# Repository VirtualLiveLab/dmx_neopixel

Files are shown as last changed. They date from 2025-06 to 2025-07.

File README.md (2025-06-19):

# dmx neopixel
DMX信号をNeoPixelの信号に変換する基板

## 基板設計
- KiCad 9.0で作成
- [JLCPCB](https://jlcpcb.com)に発注
- 部品はほぼ全て秋月電子通商にて購入可能(XLRのレセプタクルのみサウンドハウスで購入)

## ファームウェア書き込み
- [PlatformIO Core](https://docs.platformio.org/en/latest/core/index.html)をインストール
  - [get-platformio.py](https://raw.githubusercontent.com/platformio/platformio-core-installer/master/get-platformio.py)をダウンロードしてPython3で実行
- USBで基板をPCに接続
- 書き込みコマンド実行

```bash
cd ./platformio/
pio run
```

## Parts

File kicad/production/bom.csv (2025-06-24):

Designator | Footprint | Quantity | Value | LCSC Part #
C1, C2, C5, C8 | 0603 | 4 | 0.1u
C3, C6, C7 | 0603 | 3 | 1u
C4 | 0603 | 1 | 10u
D1, D2 | D_SOD-123F | 2 | SS2040FL
D3 | LED_WS2812B-2020_PLCC4_2.0x2.0mm | 1 | WS2812C-2020
F1 | Fuse_Bourns_MF-RHT050 | 1 | MF-R050
J1 | BarrelJack_Horizontal | 1 | Jack-DC
J2 | USB_C_Receptacle_GCT_USB4105-xx-A_16P_TopMnt_Horizontal | 1 | USB_C_Receptacle_USB2.0_16P
J3 | JST_XH_S2B-XH-A_1x02_P2.50mm_Horizontal | 1 | Conn_01x02_Pin
J4 | Jack_XLR_Neutrik_NC3MAH_Horizontal | 1 | NC3MAH
J5 | Jack_XLR_Neutrik_NC3FAH2_Horizontal | 1 | NC3FAH2
Q1 | SOT-23 | 1 | BSS138
R1, R2 | 0603 | 2 | 5.1k
R3, R4, R5 | 0603 | 3 | 10k
SW1 | SW_SPST_PTS810 | 1 | SW_Push
SW2 | SW_DIP_SPSTx10_Slide_6.7x26.96mm_W7.62mm_P2.54mm_LowProfile | 1 | SW_DIP_x10
U1 | SIP3_11.6x8.5mm | 1 | BP5293-50
U2 | SOT-23 | 1 | AP7333-33SA
U3 | ESP32-C3-WROOM-02 | 1 | ESP32-C3-WROOM-02
U4 | SOIC-8_3.9x4.9mm_P1.27mm | 1 | MAX3485

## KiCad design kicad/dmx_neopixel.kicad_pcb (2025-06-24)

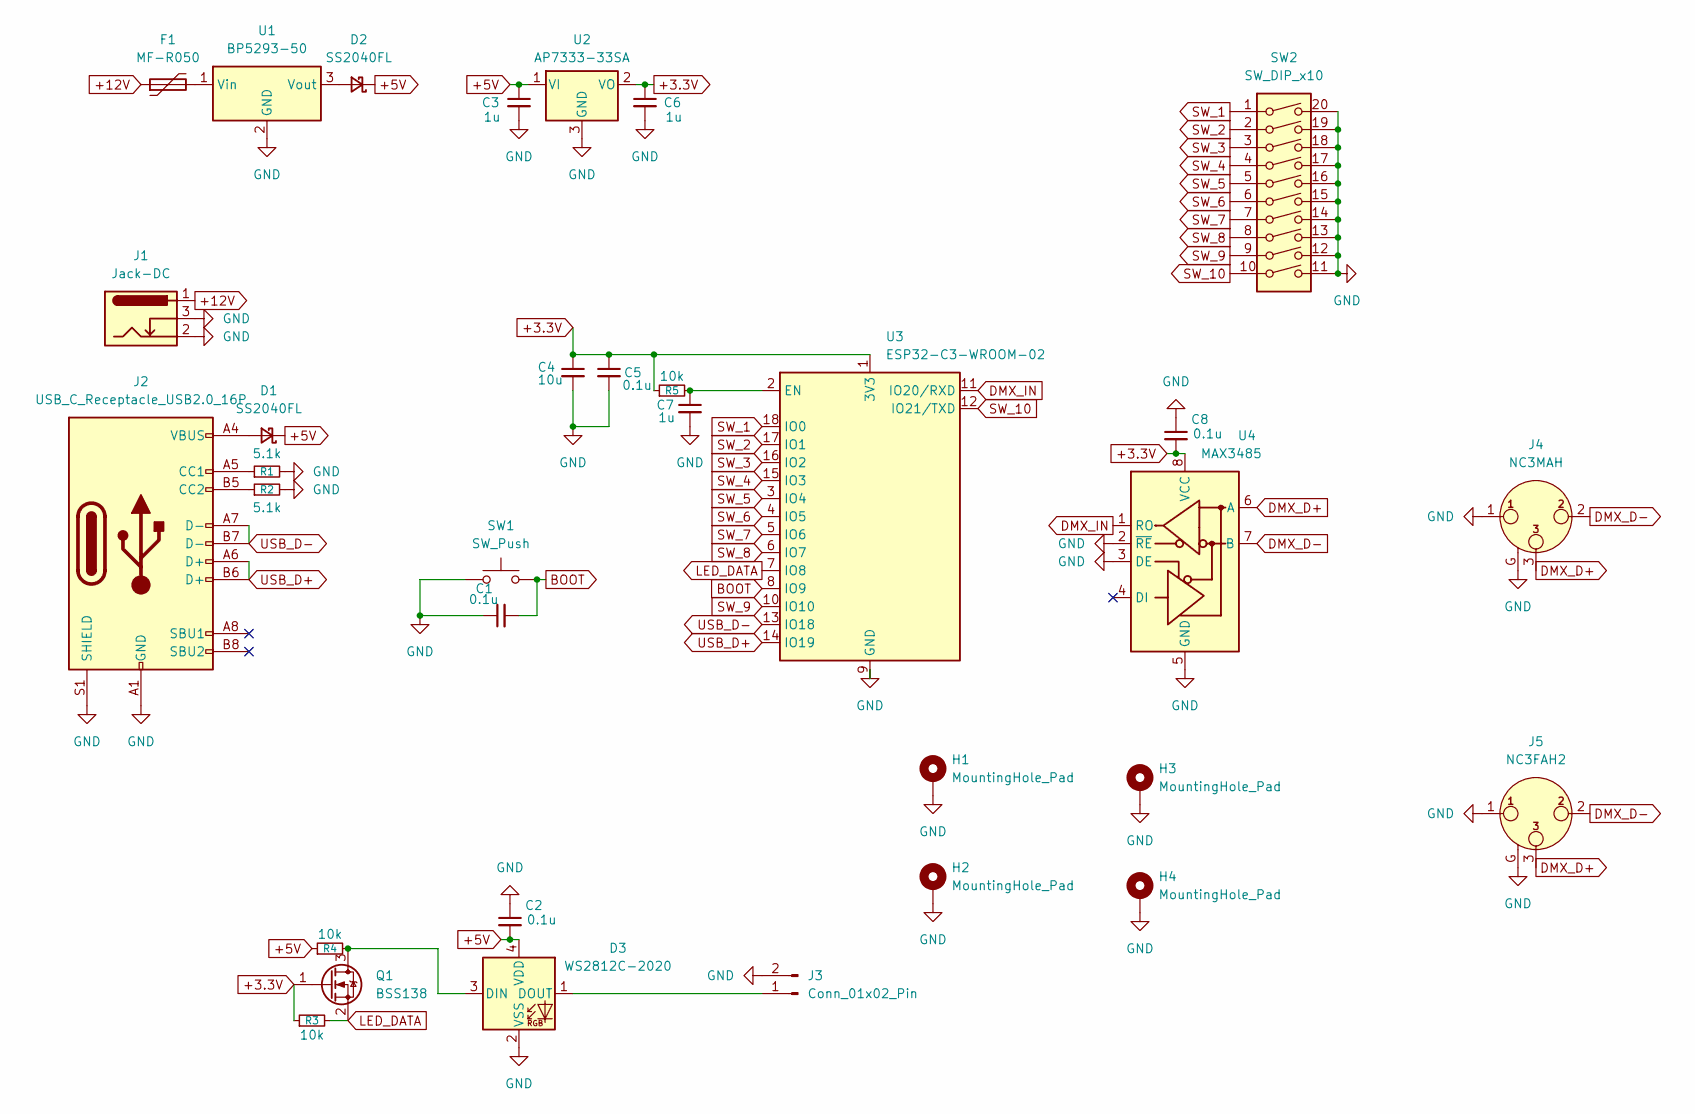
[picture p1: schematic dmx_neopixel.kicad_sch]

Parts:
C1, C2, C5, C8: 0.1u; C_0603_1608Metric_Pad1.08x0.95mm_HandSolder
C3, C6, C7: 1u; C_0603_1608Metric_Pad1.08x0.95mm_HandSolder
C4: 10u; C_0603_1608Metric_Pad1.08x0.95mm_HandSolder
D1, D2: SS2040FL; D_SOD-123F
D3: WS2812C-2020; LED_WS2812B-2020_PLCC4_2.0x2.0mm
F1: MF-R050; Fuse_Bourns_MF-RHT050
H1, H2, H3, H4: MountingHole_Pad; MountingHole_3.2mm_M3_Pad_TopBottom
J1: Jack-DC; BarrelJack_Horizontal
J2: USB_C_Receptacle_USB2.0_16P; USB_C_Receptacle_GCT_USB4105-xx-A_16P_TopMnt_Horizontal
J3: Conn_01x02_Pin; JST_XH_S2B-XH-A_1x02_P2.50mm_Horizontal
J4: NC3MAH; Jack_XLR_Neutrik_NC3MAH_Horizontal
J5: NC3FAH2; Jack_XLR_Neutrik_NC3FAH2_Horizontal
Q1: BSS138; SOT-23
R1, R2: 5.1k; R_0603_1608Metric_Pad0.98x0.95mm_HandSolder
R3, R4, R5: 10k; R_0603_1608Metric_Pad0.98x0.95mm_HandSolder
SW1: SW_Push; SW_SPST_PTS810
SW2: SW_DIP_x10; SW_DIP_SPSTx10_Slide_6.7x26.96mm_W7.62mm_P2.54mm_LowProfile
U1: BP5293-50; SIP3_11.6x8.5mm
U2: AP7333-33SA; SOT-23
U3: ESP32-C3-WROOM-02
U4: MAX3485; SOIC-8_3.9x4.9mm_P1.27mm

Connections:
+3.3V: C4.1, C5.1, C6.1, C8.2, Q1.1 (G), R3.1, R5.1, U2.2 (VO), U3.1 (3V3), U4.8 (VCC)
+5V: C2.2, C3.1, D1.1 (K), D2.1 (K), D3.4 (VDD), R4.1, U2.1 (VI)
+12V: F1.1, J1.1
BOOT: C1.2, SW1.2, U3.8 (IO9)
DMX_D+: J4.3, J5.3, U4.6 (A)
DMX_D-: J4.2, J5.2, U4.7 (B)
DMX_IN: U3.11 (IO20/RXD), U4.1 (RO)
GND: C1.1, C2.1, C3.2, C4.2, C5.2, C6.2, C7.2, C8.1, D3.2 (VSS), H1.1, H2.1, H3.1, H4.1, J1.2, J1.3, J2.A1 (GND), J2.A12 (GND), J2.B1 (GND), J2.B12 (GND), J2.S1 (SHIELD), J3.2, J4.1, J4.G, J5.1, J5.G, R1.2, R2.2, SW1.1, SW2.11, SW2.12, SW2.13, SW2.14, SW2.15, SW2.16, SW2.17, SW2.18, SW2.19, SW2.20, U1.2 (GND), U2.3 (GND), U3.9 (GND), U3.19 (GND), U4.2 (~RE), U4.3 (DE), U4.5 (GND)
LED_DATA: Q1.2 (S), R3.2, U3.7 (IO8)
unnamed: D1.2 (A), J2.A4 (VBUS), J2.A9 (VBUS), J2.B4 (VBUS), J2.B9 (VBUS)
unnamed: D2.2 (A), U1.3 (Vout)
unnamed: D3.3 (DIN), Q1.3 (D), R4.2
unnamed: D3.1 (DOUT), J3.1
unnamed: J2.A5 (CC1), R1.1
unnamed: J2.B5 (CC2), R2.1
unnamed: F1.2, U1.1 (Vin)
unnamed: C7.1, R5.2, U3.2 (EN)
SW_1: SW2.1, U3.18 (IO0)
SW_2: SW2.2, U3.17 (IO1)
SW_3: SW2.3, U3.16 (IO2)
SW_4: SW2.4, U3.15 (IO3)
SW_5: SW2.5, U3.3 (IO4)
SW_6: SW2.6, U3.4 (IO5)
SW_7: SW2.7, U3.5 (IO6)
SW_8: SW2.8, U3.6 (IO7)
SW_9: SW2.9, U3.10 (IO10)
SW_10: SW2.10, U3.12 (IO21/TXD)
USB_D+: J2.A6 (D+), J2.B6 (D+), U3.14 (IO19)
USB_D-: J2.A7 (D-), J2.B7 (D-), U3.13 (IO18)

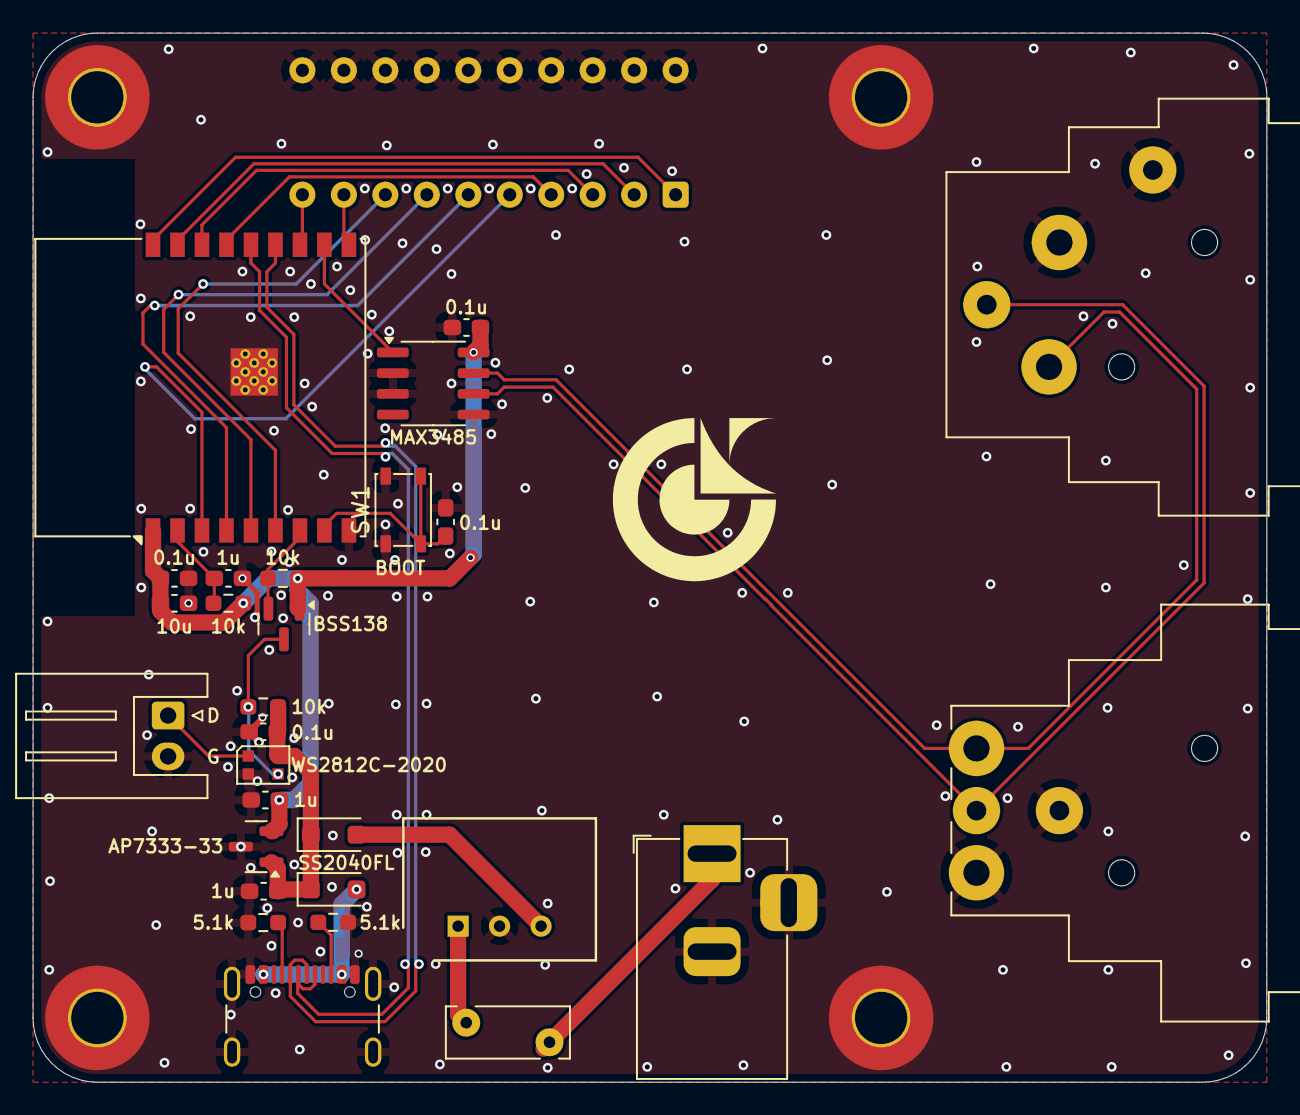
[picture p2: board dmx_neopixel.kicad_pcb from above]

Board: 2 copper layers, 75.6 x 64.3 mm, 33 parts (1 on the bottom side), 29 nets.

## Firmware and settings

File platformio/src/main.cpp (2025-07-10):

#include <Arduino.h>
#include <esp_dmx.h>
#include <NeoPixelBus.h>
#include <Preferences.h>
#include <CRC32.h>
#include <PacketSerial.h>

#define VERSION 0x20  // v2.0
#define DATASIZE 2041
#define BUFFSIZE 4096
#define LEDNUM 961
#define LEDPIN 8
#define DMXPIN 20
#define INDICATOR_BRIGHTNESS 10

NeoPixelBus<NeoGrbFeature, NeoEsp32Rmt0Ws2812xMethod> leds(LEDNUM, LEDPIN);
PacketSerial_<COBS, 0, BUFFSIZE> packetSerial;
Preferences preferences;
uint8_t cache[DATASIZE];
byte dmxData[DMX_PACKET_SIZE];
SemaphoreHandle_t showSemaphore;

volatile unsigned long retry = 0;

uint8_t validateCRC(const uint8_t* buffer, size_t size) {
  uint32_t crcInBuff = ((uint32_t)buffer[size - 4] << 24) |
    ((uint32_t)buffer[size - 3] << 16) |
    ((uint32_t)buffer[size - 2] << 8)  |
    ((uint32_t)buffer[size - 1]);
  uint32_t crc = CRC32::calculate(buffer, size - 4);
  if (crcInBuff != crc) return 1;
  return 0;
}

void onPacketReceived(const uint8_t* buffer, size_t size) {
  uint8_t resBuff[DATASIZE + 6];
  resBuff[0] = VERSION;
  if (validateCRC(buffer, size) == 0) {
    if (buffer[1] == 0x00) {
      resBuff[1] = 0x00;
      memcpy(resBuff + 2, cache, DATASIZE);
      uint32_t crc = CRC32::calculate(resBuff, DATASIZE + 2);
      resBuff[DATASIZE + 2] = (crc >> 24);
      resBuff[DATASIZE + 3] = (crc >> 16);
      resBuff[DATASIZE + 4] = (crc >> 8);
      resBuff[DATASIZE + 5] = crc;
      packetSerial.send(resBuff, DATASIZE + 6);
      return;
    } else if (buffer[0] == VERSION && buffer[1] == 0x01) {
      memcpy(cache, buffer + 2, DATASIZE);
      if (preferences.putBytes("data", cache, DATASIZE) > 0) {
        resBuff[1] = 0x00;
        uint32_t crc = CRC32::calculate(resBuff, 2);
        resBuff[2] = (crc >> 24);
        resBuff[3] = (crc >> 16);
        resBuff[4] = (crc >> 8);
        resBuff[5] = crc;
        packetSerial.send(resBuff, 6);
        return;
      }
    }
  }
  resBuff[1] = 0x01;
  uint32_t crc = CRC32::calculate(resBuff, 2);
  resBuff[2] = (crc >> 24);
  resBuff[3] = (crc >> 16);
  resBuff[4] = (crc >> 8);
  resBuff[5] = crc;
  packetSerial.send(resBuff, 6);
}

void showTask(void* pvParameters) {
  TickType_t lastWake = xTaskGetTickCount();
  for (;;) {
    if (xSemaphoreTake(showSemaphore, portMAX_DELAY) == pdTRUE) {
      if (leds.CanShow()) {
        leds.Show();
      }
    }
    vTaskDelayUntil(&lastWake, pdMS_TO_TICKS(10));
  }
}

void dmxTask(void* pvParameters) {
  bool dmxIsConnected = false;
  for (;;) {
    dmx_packet_t packet;

    leds.ClearTo(RgbColor(0, 0, 0));
    leds.SetPixelColor(0, RgbColor(INDICATOR_BRIGHTNESS, 0, 0));

    if (dmx_receive(DMX_NUM_1, &packet, DMX_TIMEOUT_TICK)) {
      if (!packet.err) {
        retry = 0;
        if (!dmxIsConnected) {
          dmxIsConnected = true;
        }
        leds.SetPixelColor(0, RgbColor(0, INDICATOR_BRIGHTNESS, 0));
        dmx_read(DMX_NUM_1, dmxData, packet.size);

        float colorScale = cache[0] / 255.0f;
        size_t c = 1;
        while (c + 2 < packet.size && (4 * (c - 1) + 4) < DATASIZE) {
          uint16_t start = ((uint16_t)cache[4 * (c - 1) + 1] << 8) | ((uint16_t)cache[4 * (c - 1) + 2]);
          uint16_t end = ((uint16_t)cache[4 * (c - 1) + 3] << 8) | ((uint16_t)cache[4 * (c - 1) + 4]);
          if (start * end == 0) {
            c++;
            continue;
          }
          if (start > LEDNUM - 1) {
            start = LEDNUM - 1;
          }
          if (end > LEDNUM - 1) {
            end = LEDNUM - 1;
          }
          if (start > end) {
            start ^= end;
            end ^= start;
            start ^= end;
          }
          uint8_t r = dmxData[c];
          uint8_t g = dmxData[c + 1];
          uint8_t b = dmxData[c + 2];
          if (r + g + b > 0) {
            RgbColor color(
                (uint8_t)(r * colorScale),
                (uint8_t)(g * colorScale),
                (uint8_t)(b * colorScale)
                );
            for (uint16_t k = start; k <= end; k++) {
              leds.SetPixelColor(k, color);
            }
          }
          c += 3;
        }
      }
    } else if (dmxIsConnected) {
      dmxIsConnected = false;
      retry = millis();
    }
    xSemaphoreGive(showSemaphore);
    vTaskDelay(pdMS_TO_TICKS(1));
  }
}

void setup() {
  Serial.begin(115200);
  Serial.setRxBufferSize(BUFFSIZE);
  
  packetSerial.setStream(&Serial);
  packetSerial.setPacketHandler(&onPacketReceived);

  preferences.begin("store");
  if (preferences.isKey("data")) {
    preferences.getBytes("data", cache, DATASIZE);
  } else {
    memset(cache, 0, DATASIZE);
    preferences.putBytes("data", cache, DATASIZE);
  }

  dmx_config_t config = DMX_CONFIG_DEFAULT;
  dmx_personality_t personalities[] = {
    {3, "RGB"}
  };
  uint8_t personality_count = 1;
  dmx_driver_install(DMX_NUM_1, &config, personalities, personality_count);
  dmx_set_pin(DMX_NUM_1, -1, DMXPIN, -1);

  leds.Begin();
  leds.SetPixelColor(0, RgbColor(INDICATOR_BRIGHTNESS, INDICATOR_BRIGHTNESS, 0));
  leds.Show();

  showSemaphore = xSemaphoreCreateBinary();
  xTaskCreate(dmxTask, "DMX Task", 2048, NULL, 1, NULL);
  xTaskCreate(showTask, "Show Task", 2048, NULL, 1, NULL);
}

void loop() {
  packetSerial.update();
  if (retry > 0 && millis() - retry > 1000) {
    ESP.restart();
  }
  delay(1);
}

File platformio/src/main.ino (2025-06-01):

#include <esp_dmx.h>
#include <Adafruit_NeoPixel.h>

#define SWPINS ((uint8_t[10]){10, 9, 8, 7, 6, 5, 4, 3, 2, 11})
#define LEDPIN 1
#define DMXPIN 44
#define BRIGHTNESS 10
#define LEDNUM 30
#define LEDGRP ((int[][3]){{1, 5, 6}, {1, 30, 1}, {16, 15, 1}})
// channelMap {{1, 5}, {6, 10}, {11, 15}, {16, 20}, {21, 25}, {26, 30}, {1, 30}, {16, 30}}
//        dmx  |0,1,2  |3,4,5   |6,7,8    |9,10,11  |12,13,14 |15,16,17 |18,19,20|21,22,23 (+ startChannel)

Adafruit_NeoPixel leds(LEDNUM + 1, LEDPIN, NEO_GRB + NEO_KHZ800);

dmx_port_t dmxPort = 1;
byte data[DMX_PACKET_SIZE];

bool dmxIsConnected = false;
int channelNum;
int **channelMap;

void readSW(int *startChannel) {
  *startChannel = 0;
  for (int i = sizeof(SWPINS) - 1; i >= 0; i--) {
    if (!digitalRead(SWPINS[i])) {
      *startChannel += 1;
    }
    if (i > 0) {
      *startChannel <<= 1;
    }
  }
}

void setup() {
  Serial.begin(115200);

  dmx_config_t config = DMX_CONFIG_DEFAULT;
  dmx_personality_t personalities[] = {
    {1, "Default Personality"}
  };
  int personality_count = 1;
  dmx_driver_install(dmxPort, &config, personalities, personality_count);
  dmx_set_pin(dmxPort, -1, DMXPIN, -1);

  for (int i = 0; i < sizeof(SWPINS); i++) {
    pinMode(SWPINS[i], INPUT_PULLUP);
  }

  for (int i = 0; i < sizeof(LEDGRP) / sizeof(LEDGRP[0]); i++) {
    channelNum += LEDGRP[i][2];
  }
  channelMap = (int**)malloc(sizeof(int) * channelNum);
  int c = 0;
  for (int i = 0; i < sizeof(LEDGRP) / sizeof(LEDGRP[0]); i++) {
    for (int j = 0; j < LEDGRP[i][2]; j++) {
      channelMap[c] = (int*)malloc(sizeof(int) * 2);
      channelMap[c][0] = LEDGRP[i][0] + LEDGRP[i][1] * j;
      channelMap[c][1] = LEDGRP[i][0] + LEDGRP[i][1] * (j + 1) - 1;
      c++;
    }
  }

  leds.begin();
  leds.setBrightness(BRIGHTNESS);
  leds.clear();
  leds.setPixelColor(0, leds.Color(255, 255, 0));
  leds.show();
}

void loop() {
  int startChannel;
  readSW(&startChannel);
  dmx_packet_t packet;
  leds.clear();
  leds.setPixelColor(0, leds.Color(255, 0, 0));
  if (dmx_receive(dmxPort, &packet, DMX_TIMEOUT_TICK)) {
    if (!packet.err) {
      if (!dmxIsConnected) {
        dmxIsConnected = true;
      }
      leds.setPixelColor(0, leds.Color(0, 255, 0));
      dmx_read(dmxPort, data, packet.size);
      for (int i = 1; i <= 512; i++) {
        Serial.print(data[i]); Serial.print(" ");
      }
      Serial.println("");

      for (int c = 0; c < channelNum; c++) {
        for (int k = channelMap[c][0]; k <= channelMap[c][1]; k++) {
          if (startChannel + c * 3 + 2 > 512 || k > LEDNUM) break;
          if (data[startChannel + c * 3] + data[startChannel + c * 3 + 1] + data[startChannel + c * 3 + 2] > 0) {
            leds.setPixelColor(k, leds.Color(data[startChannel + c * 3], data[startChannel + c * 3 + 1], data[startChannel + c * 3 + 2]));
          }
        }
      }
    }
  } else if (dmxIsConnected) {
    ESP.restart();
  }
  leds.show();
}

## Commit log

2025-05-10 feat: add kicad files
    [bom.csv, designators.csv, dmx_neopixel.kicad_pcb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]
2025-05-28 feat: v0.2の基板を作成
    [bom.csv, designators.csv, dmx_neopixel.kicad_pcb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]
2025-06-01 feat: 割り当ての設定方法を変更
2025-06-02 feat: 拡張子などを変更
2025-06-02 feat: 小変更
2025-06-02 feat: USBでのデバッグを無効にできるようにした
2025-06-02 fix: 構文エラー修正
2025-06-02 feat: コードの最適化
2025-06-02 feat: 不要なループを排除
2025-06-03 feat: インジケーターの明るさとテープの明るさを分離
2025-06-06 feat: ESP32をC3に変更
    [bom.csv, designators.csv, dmx_neopixel.kicad_pcb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]
2025-06-19 feat: v1.0の基板データを追加
    [bom.csv, designators.csv, dmx_neopixel.kicad_pcb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]
2025-06-19 feat: READMEを作成
2025-06-19 feat: READMEを更新
2025-06-24 feat: 基板データ更新
    [bom.csv, dmx_neopixel.kicad_pcb, dmx_neopixel.kicad_sch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]
2025-07-03 feat: PCから設定できるファームウェアを作成
2025-07-08 feat: パフォーマンス改善
2025-07-09 feat: ガンマ補正無効化
2025-07-10 feat: dmx処理の小修正
2025-07-10 feat: CRCの処理の最適化
